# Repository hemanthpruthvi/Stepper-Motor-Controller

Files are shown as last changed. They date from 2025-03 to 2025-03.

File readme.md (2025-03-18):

# Generic Stepper Motor Controller for Multi-Axis Motion
The project describes a simple and complete solution to multi-axis motion control using generic stepper-motor based mounts with off-the-shelf motor drives, a system that looks like the following.  

Motion controller &rarr; Stepper motor drive &rarr; Motorized rotation/translation stage

The motion controller has two aspects:  
1. Hardware: design files for dsPIC micro-controller based custom board
2. Firmware: embedded-C program that implements the motion controls

## Hardware
The central element is a dsPIC micro-controller with two UART ports and several I/O ports that enable control of upto 3 drives at a time by sending correspinding pulse trains (drive IDs 1-3). Up to three of such motion controllers can be connected in daisy chain thus being able to control upto nine drives (drive IDs 1-9). The number of daisy chains is only a firmware limitation due to how the drives are numbered. A better numbering scheme should allow for more expansion.

The directory `Hardware` contains the design files. Hardware circuitry is designed using `KiCAD` program. The final `GERBER` file should be enough to produce the custom printed circuit boards.

## Firmware
The firmware is programmed in Embedded-C using `MPLABX IDE` with a header that is specific to the micro-controller of choice. The directory `Firmware` contains the source code as well as the compiled output. The firmware is written into the hardware using `PIKIT 3` programmer tool. The `HEX` file to be written to hardware is located at`<firmware directory>/dist/default/Production`.

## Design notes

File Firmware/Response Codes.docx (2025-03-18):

Stepper motor controller with home positioning sensor

1. Description

The stepper motor controller is designed to control three stepper motors corresponding to three rotation stages. It can be used to control linear stages as well but, as limit switch functionality is not provided, other precautions must be taken to facilitate it. It has dsPIC33fj128gp802 (https://www.microchip.com/wwwproducts/en/dsPIC33FJ128GP802) micro-controller. Two serial ports are provided: one communicate with slave & one with master. Up to three controllers can be used in tandem. Three motor controller ports are provided that include & homing detection too.

2. Sent Commands & responses

Configuration of serial port is baud rate: 115200, parity: N, stop bits: 1 and data bits: 8. Set of serial commands to operate the controller are given below. All the commands must start with ‘<’ and end with ‘>’ as shown in the table.

n: motor number (1, 2 or 3)

f: frequency of the pulses (1 to 2¹⁶-1)

p: number of pulses (1 to 2³²-1)

Command sent | Return | Function
<nH> | nH | Go gome in positive direction e.g., <1H>
<nh> | nh | Go home in the negative direction e.g., <1h>
<nQ> | nQ | Halt the motor e.g., <1Q>
<nFf> | nA | Change the frequency of the pulses i.e. speed e.g., <1F1000>
<n+p> | nA, nR | Rotate the motor by given number of pulses, in positive direction e.g., <1+1000>
<n-p> | nA, nR | Rotate the motor by given number of pulses, in negative direction e.g., <1-1000>

3. Responses & diagnosis

Possible responses and their cause is given below. All the responses are of 4 character length: two alphanumerical characters superseded by a newline character (‘\n’) and a null character (‘\0’). Hence, these responses can be read as lines.

Command received | Diagnosis
nH | Reached home in positive direction
nh | Reached home in negative direction
nQ | Motor halted
nA | Command is acknowledged
MA | Command is acknowledged by the master and it is forwarded to the slave controller
nR | All the pulses have been sent
nX | Motor number is right but wrong function command
MX | Wrong command altogether

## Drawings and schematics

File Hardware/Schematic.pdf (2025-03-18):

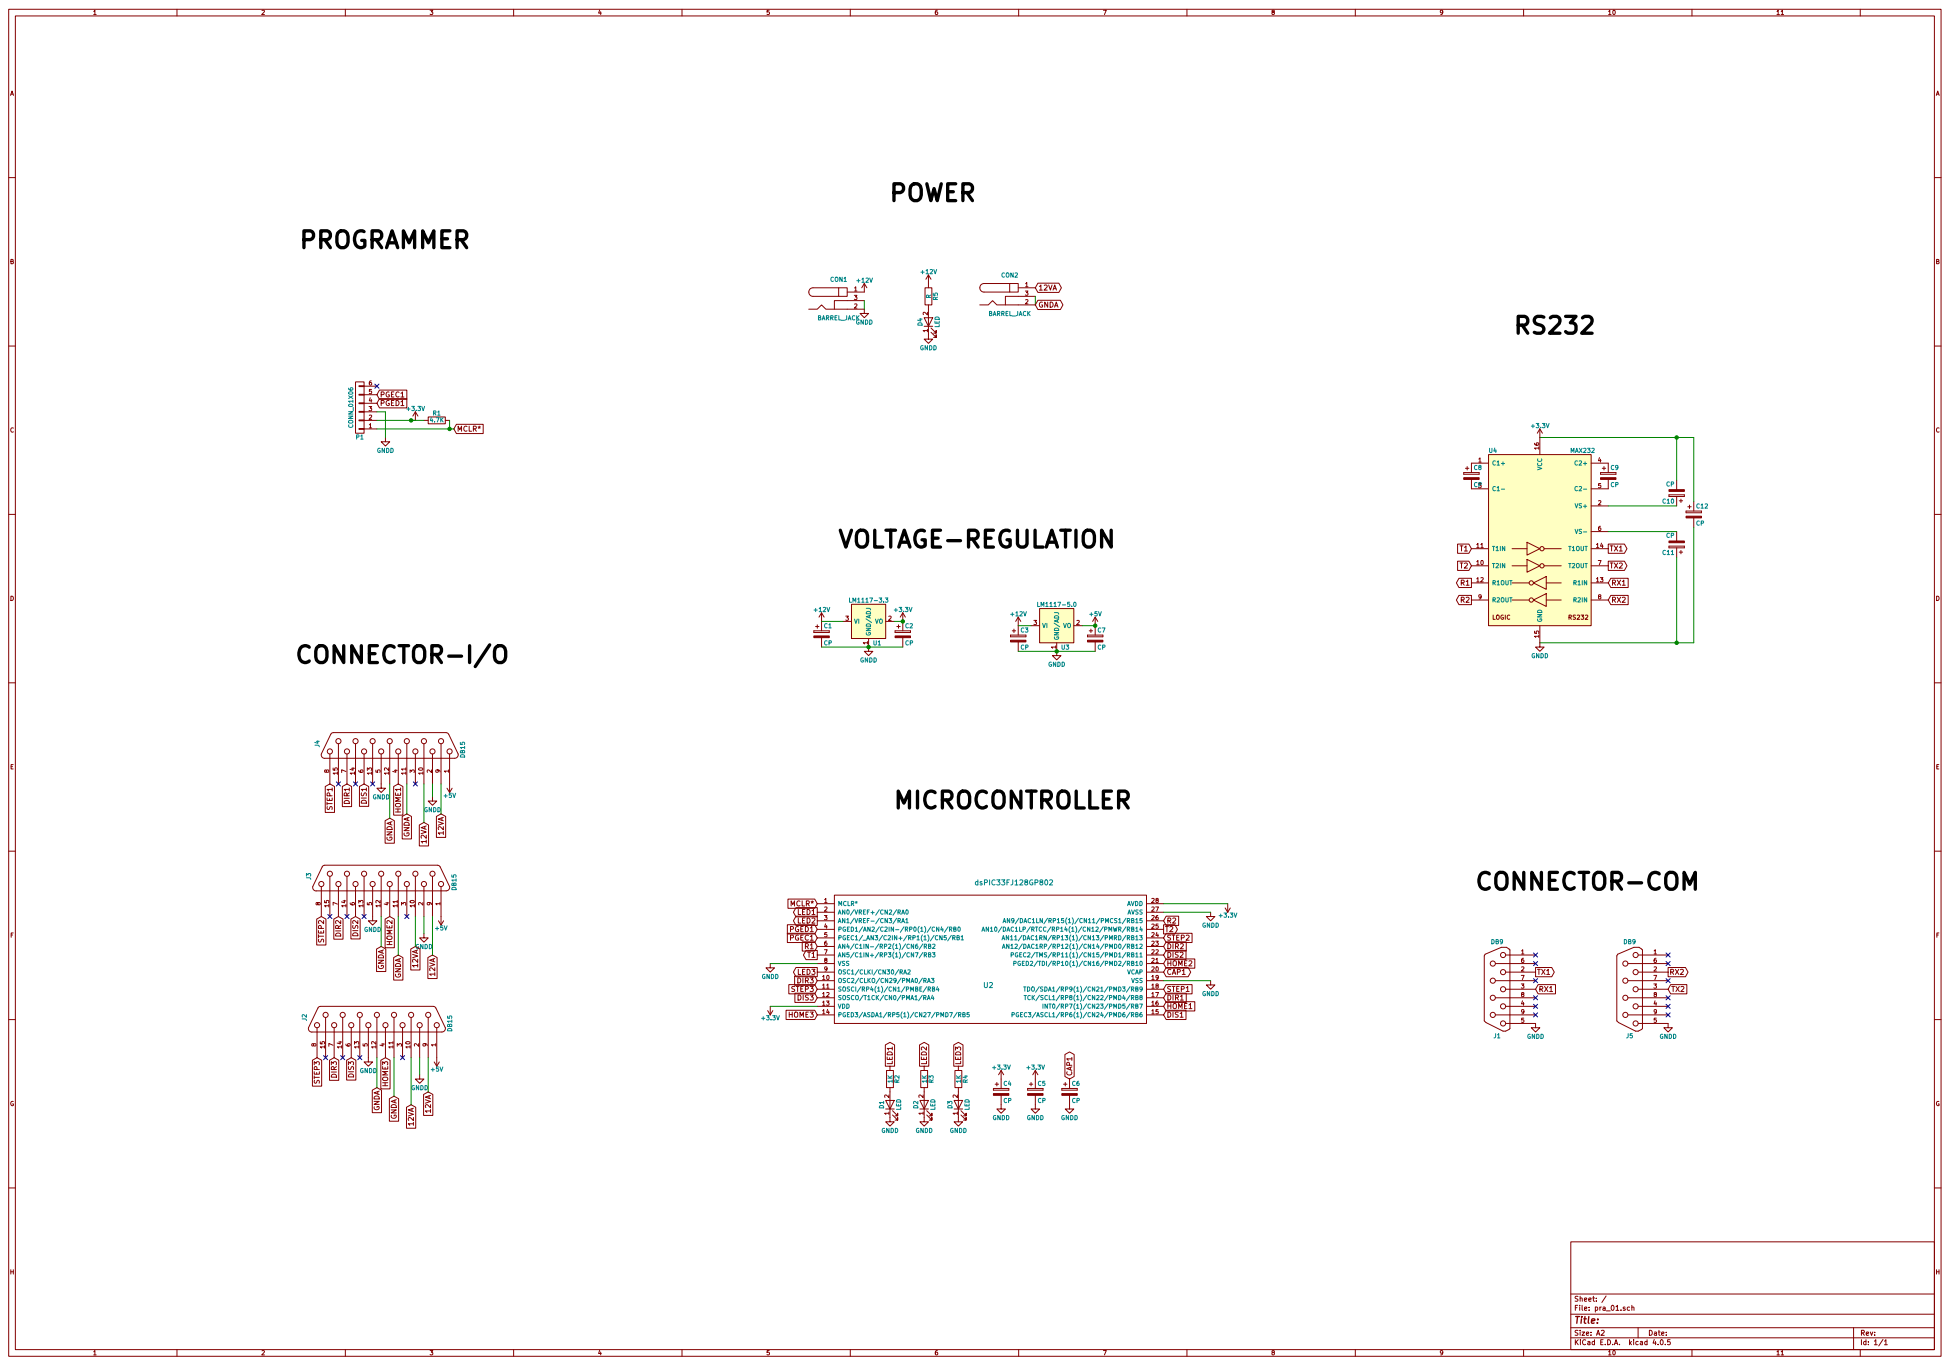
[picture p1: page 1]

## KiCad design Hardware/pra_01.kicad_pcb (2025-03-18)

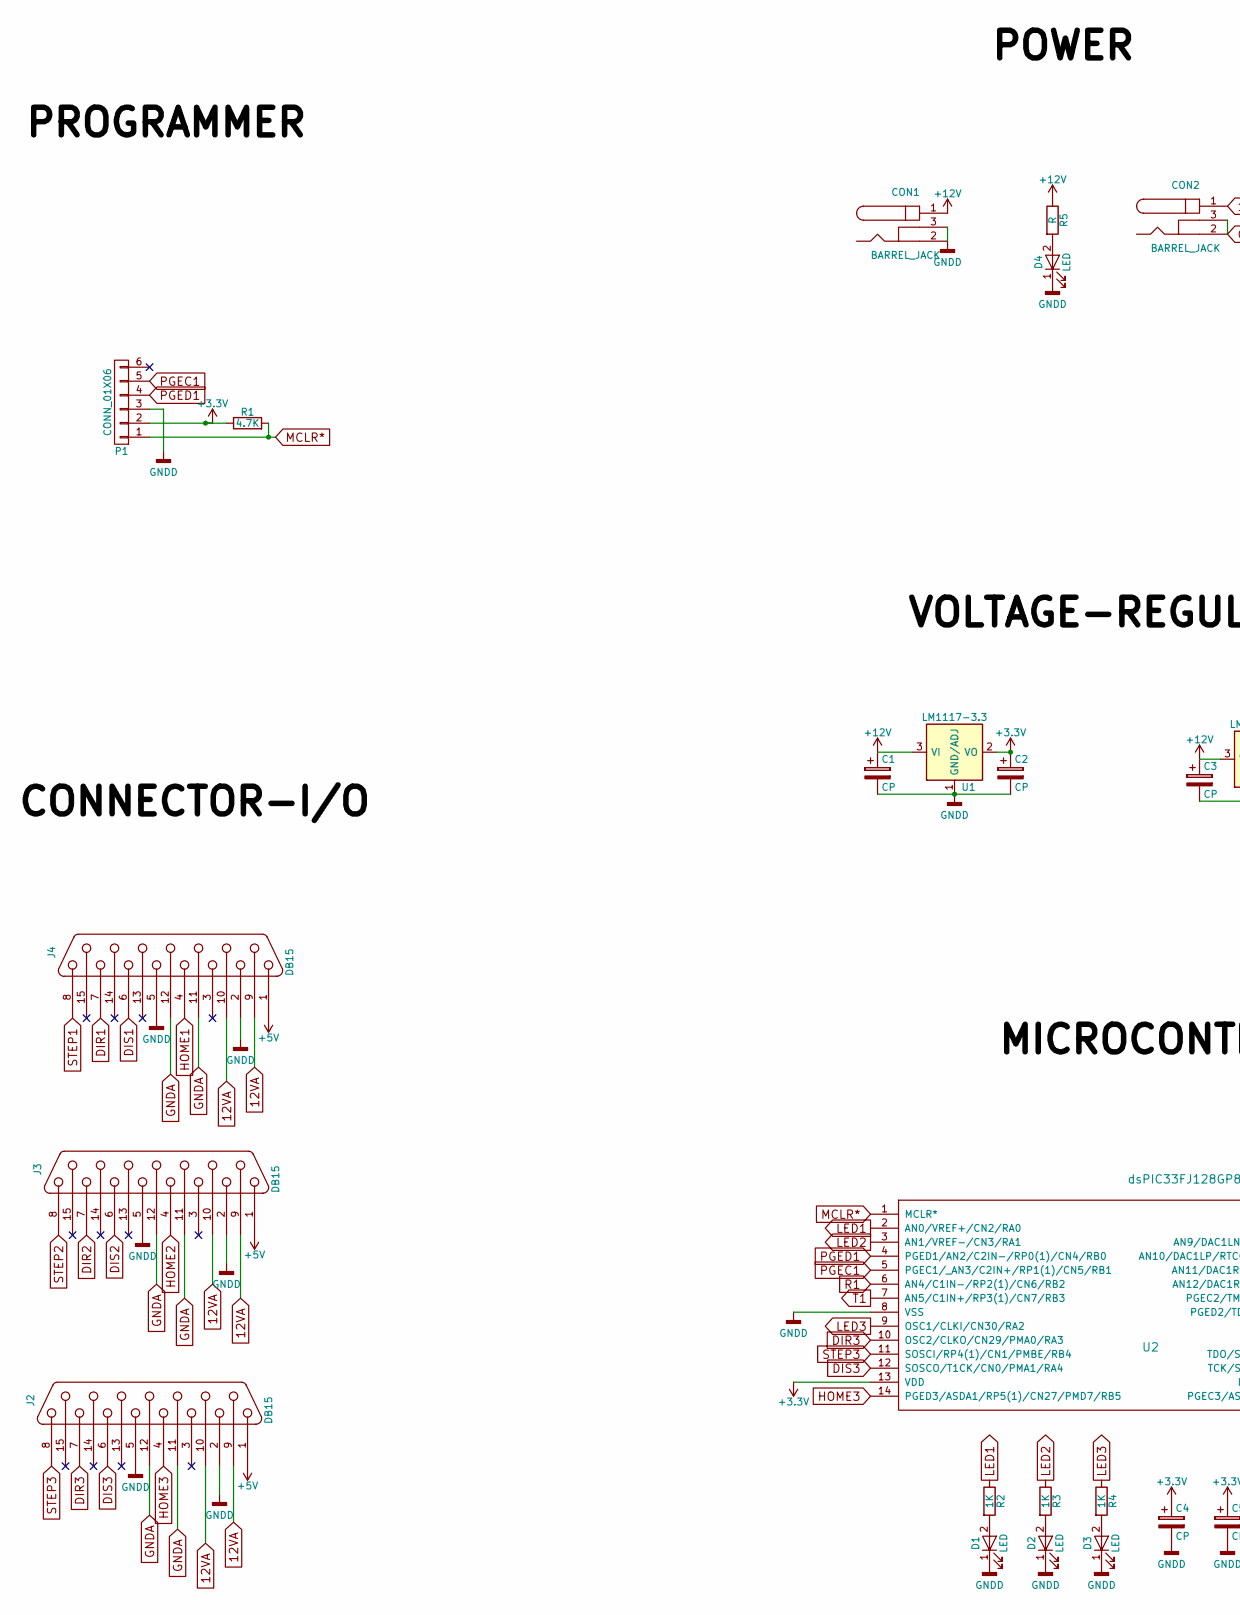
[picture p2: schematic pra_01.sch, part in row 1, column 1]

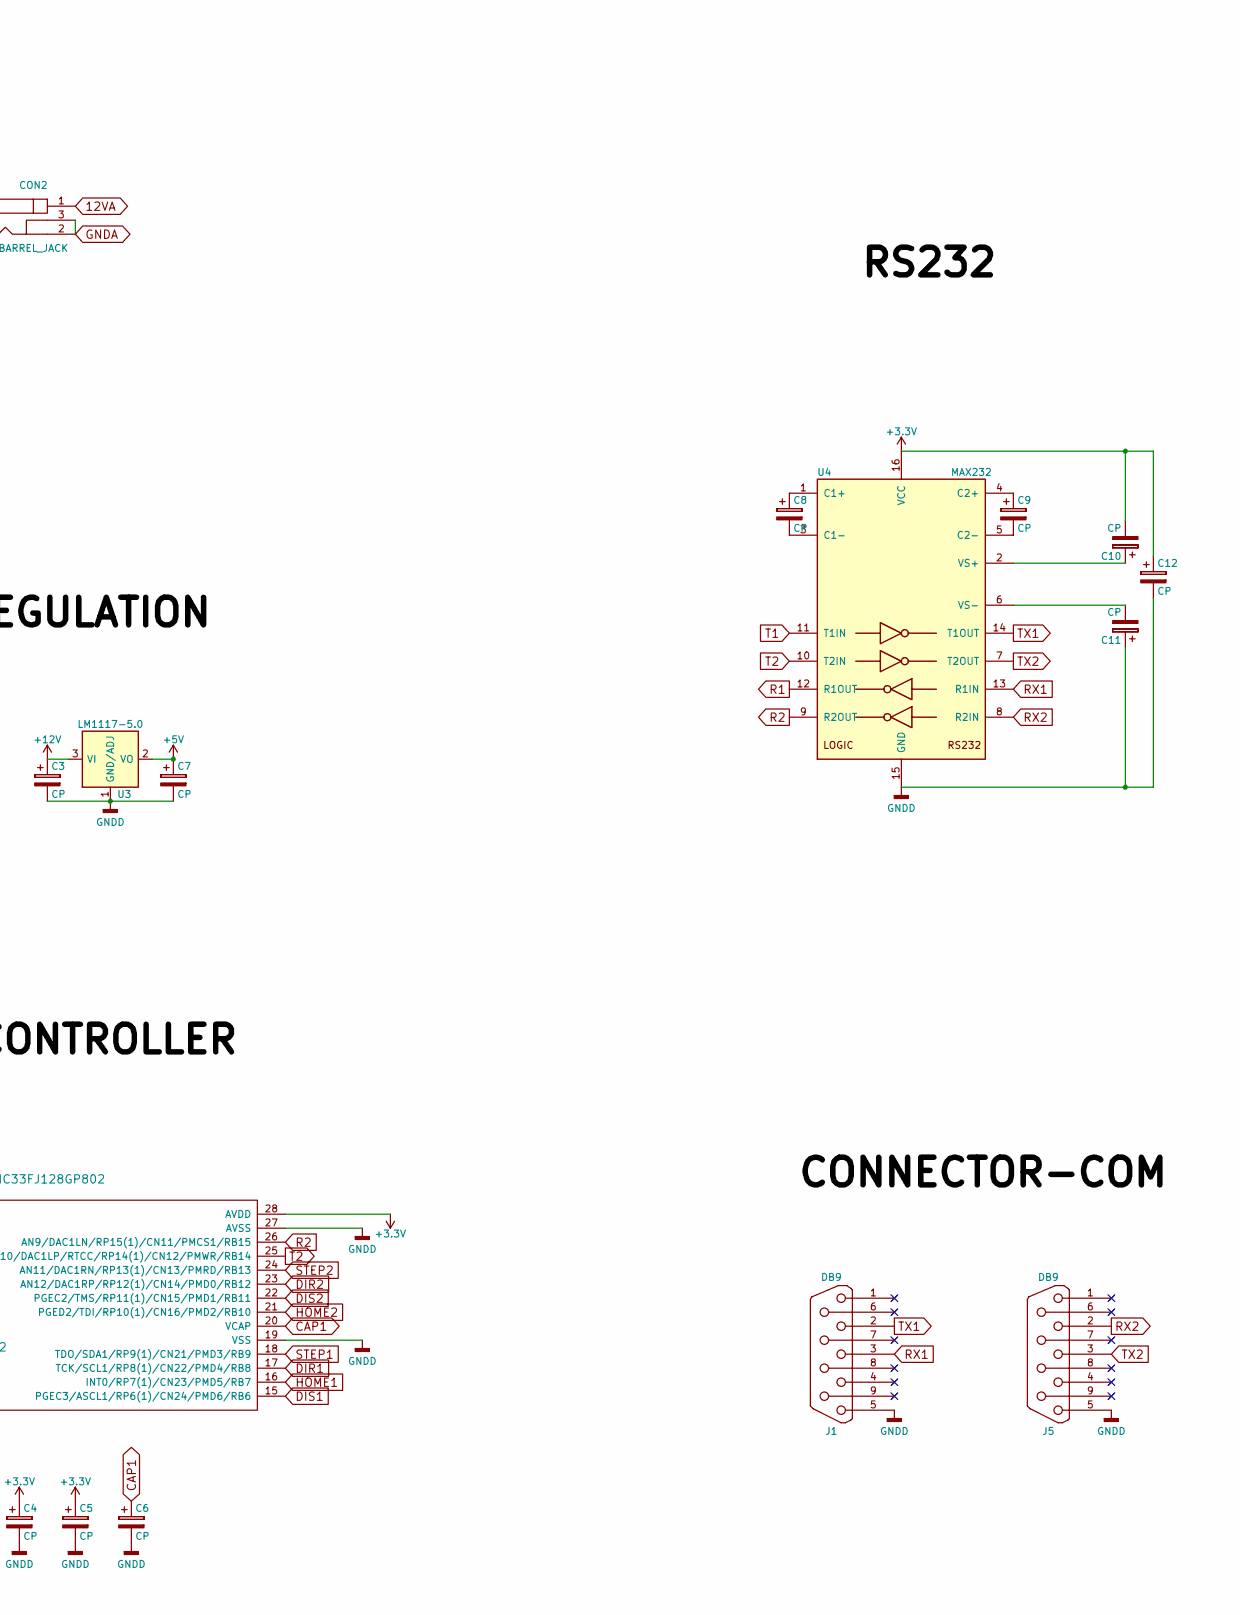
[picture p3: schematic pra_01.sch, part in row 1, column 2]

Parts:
C1, C2, C3, C6, C7: CP; CP_Radial_D5.0mm_P2.50mm
C4, C5, C8, C9, C10, C11, C12: CP; CP_Radial_Tantal_D5.0mm_P2.50mm
CON1, CON2: BARREL_JACK
D1, D2, D3: LED; LED_1206
D4: LED; LED_D5.0mm
J1: DB9; DB9FC
J2, J3, J4: DB15; DB15FC
J5: DB9; DB9MC
P1: CONN_01X06; PINHEAD1-6
R1: 4.7K; R_1206_HandSoldering
R2, R3, R4: 1K; R_1206_HandSoldering
R5: R; Resistor_SMD+THTuniversal_0805to1206_RM10_HandSoldering
U1: LM1117-3.3; TO-220
U2: dsPIC33FJ128GP802; DIP-28_W7.62mm
U3: LM1117-5.0; TO-220
U4: MAX232; DIP-16_W7.62mm_LongPads

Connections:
12VA: CON2.1, J2.9, J2.10, J3.9, J3.10, J4.9, J4.10
+3V3: C2.1, C4.1, C5.1, C10.2, C12.1, P1.2, R1.1, U1.2 (VO), U1.4 (VO), U2.13 (VDD), U2.28 (AVDD), U4.16 (VCC)
+5V: C7.1, J2.1, J3.1, J4.1, U3.2 (VO), U3.4 (VO)
+12V: C1.1, C3.1, CON1.1, R5.1, U1.3 (VI), U3.3 (VI)
CAP1: C6.1, U2.20 (VCAP)
DIR1: J4.7, U2.17 (TCK/SCL1/RP8(1)/CN22/PMD4/RB8)
DIR2: J3.7, U2.23 (AN12/DAC1RP/RP12(1)/CN14/PMD0/RB12)
DIR3: J2.7, U2.10 (OSC2/CLKO/CN29/PMA0/RA3)
DIS1: J4.6, U2.15 (PGEC3/ASCL1/RP6(1)/CN24/PMD6/RB6)
DIS2: J3.6, U2.22 (PGEC2/TMS/RP11(1)/CN15/PMD1/RB11)
DIS3: J2.6, U2.12 (SOSCO/T1CK/CN0/PMA1/RA4)
GNDA: CON2.2, CON2.3, J2.11 (P111), J2.12, J3.11 (P111), J3.12, J4.11 (P111), J4.12
GNDD: C1.2, C2.2, C3.2, C4.2, C5.2, C6.2, C7.2, C11.1, C12.2, CON1.2, CON1.3, D1.1 (K), D2.1 (K), D3.1 (K), D4.1 (K), J1.5, J2.2, J2.5, J3.2, J3.5, J4.2, J4.5, J5.5, P1.3, U1.1 (GND/ADJ), U2.8 (VSS), U2.19 (VSS), U2.27 (AVSS), U3.1 (GND/ADJ), U4.15 (GND)
HOME1: J4.4, U2.16 (INT0/RP7(1)/CN23/PMD5/RB7)
HOME2: J3.4, U2.21 (PGED2/TDI/RP10(1)/CN16/PMD2/RB10)
HOME3: J2.4, U2.14 (PGED3/ASDA1/RP5(1)/CN27/PMD7/RB5)
LED1: R2.1, U2.2 (AN0/VREF+/CN2/RA0)
LED2: R3.1, U2.3 (AN1/VREF-/CN3/RA1)
LED3: R4.1, U2.9 (OSC1/CLKI/CN30/RA2)
MCLR*: P1.1, R1.2, U2.1 (MCLR*)
unnamed: C8.1, U4.1 (C1+)
unnamed: C8.2, U4.3 (C1-)
unnamed: C9.1, U4.4 (C2+)
unnamed: C9.2, U4.5 (C2-)
unnamed: C10.1, U4.2 (VS+)
unnamed: C11.2, U4.6 (VS-)
unnamed: D1.2 (A), R2.2
unnamed: D2.2 (A), R3.2
unnamed: D3.2 (A), R4.2
unnamed: D4.2 (A), R5.2
PGEC1: P1.5, U2.5 (PGEC1/_AN3/C2IN+/RP1(1)/CN5/RB1)
PGED1: P1.4, U2.4 (PGED1/AN2/C2IN-/RP0(1)/CN4/RB0)
R1: U2.6 (AN4/C1IN-/RP2(1)/CN6/RB2), U4.12 (R1OUT)
R2: U2.26 (AN9/DAC1LN/RP15(1)/CN11/PMCS1/RB15), U4.9 (R2OUT)
RX1: J1.3, U4.13 (R1IN)
RX2: J5.2, U4.8 (R2IN)
STEP1: J4.8, U2.18 (TDO/SDA1/RP9(1)/CN21/PMD3/RB9)
STEP2: J3.8, U2.24 (AN11/DAC1RN/RP13(1)/CN13/PMRD/RB13)
STEP3: J2.8, U2.11 (SOSCI/RP4(1)/CN1/PMBE/RB4)
T1: U2.7 (AN5/C1IN+/RP3(1)/CN7/RB3), U4.11 (T1IN)
T2: U2.25 (AN10/DAC1LP/RTCC/RP14(1)/CN12/PMWR/RB14), U4.10 (T2IN)
TX1: J1.2, U4.14 (T1OUT)
TX2: J5.3, U4.7 (T2OUT)

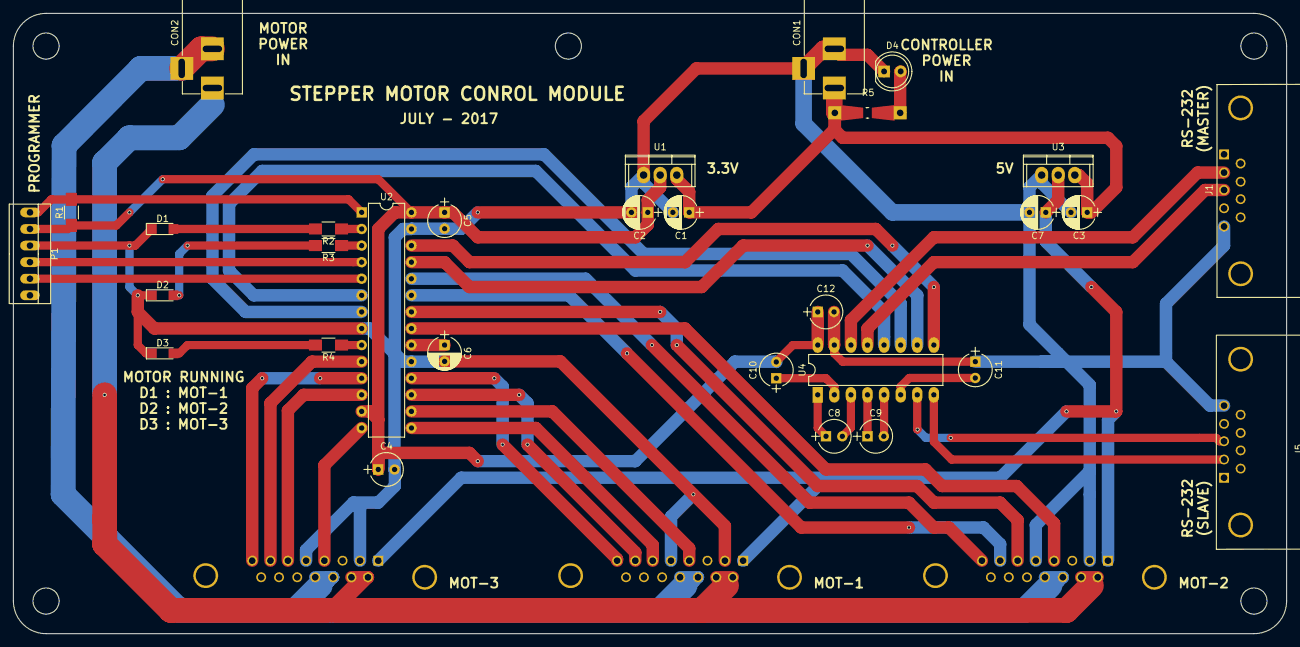
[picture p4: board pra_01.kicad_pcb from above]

Board: 2 copper layers, 195.0 x 95.0 mm, 33 parts (0 on the bottom side), 43 nets.

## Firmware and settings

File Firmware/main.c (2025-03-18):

/* 
 * File:   uart.c
 * Author: Pruthvi
 *
 * Created on June 2, 2014, 5:38 PM
 */
#include <p33FJ128GP802.h>
#include <stdio.h>
#include <stdlib.h>
#include "config.h"

unsigned char COMMAND[16];   // Command array
unsigned char SLAVE_COMMAND[16]; // Command array for slave
unsigned int COMM_IND = 0;       // Command array index
unsigned int COMM_LEN = 0;       // Command length
unsigned int COMM_REC = NO;       // Command received?
unsigned char SRESPONSE[4];
unsigned char MRESPONSE[4];

unsigned int NUMBER_MOTO = '0';    // Motor number
unsigned int FUNCTION_MOTO = '0';  // Function of drivers
unsigned long int NUMBER = 0;         // Numerical value

unsigned int MOT1_ROTAT = OFF; // Motor-1 rotation?
unsigned int MOT1_HOME = OFF;  // Motor-1 homing?
unsigned long int STEP1_NUM = 0;  // Number of steps left
unsigned long int HSTEP1_NUM = 0; // Number of toggles (half-steps)  = 2* Number of steps
unsigned int STEP1_FREQ = 1000; // Step frequency
unsigned long int POS1_CURRENT = 0; // Current value - 1

unsigned int MOT2_ROTAT = OFF; // Motor-2 rotation?
unsigned int MOT2_HOME = OFF;  // Motor-2 homing?
unsigned long int STEP2_NUM = 0;  // Number of steps left
unsigned long int HSTEP2_NUM = 0; // Number of toggles (half-steps) = 2* Number of steps
unsigned int STEP2_FREQ = 1000; // Step frequency
unsigned long int POS2_CURRENT = 0; // Current value - 2


unsigned int MOT3_ROTAT = OFF; // Motor-3 rotation?
unsigned int MOT3_HOME = OFF;  // Motor-3 homing?
unsigned long int STEP3_NUM = 0;  // Number of steps left
unsigned long int HSTEP3_NUM = 0; // Number of toggles (half-steps) = 2* Number of steps
unsigned int STEP3_FREQ = 1000; // Step frequency
unsigned long int POS3_CURRENT = 0; // Current value - 3

#pragma config POSCMD = NONE   // Primary Oscillator Mode is None
#pragma config OSCIOFNC = ON   // Oscillator pin's I/O Funcion - On
#pragma config FCKSM = CSDCMD  // Clock Switching & Monitoring - Both Disabled
#pragma config FNOSC = FRCPLL  // Oscillator select - FastRC with PLL
#pragma config FWDTEN = OFF    // Watch Dog Timer Enable - Off

void PROCESS_COMM(void);
void DELAY(int);

int main(void){
    ADPCFG = 0xFFFF;    //make ADC pins all digital
    INIT_OSCLI();   // Initiate =internal Oscillator
    INIT_INOUT();   // Input/Output
    INIT_UART1();   // UART-1
    INIT_UART2();   // UART-2
    INIT_TIMR2();   // Timer-2
    INIT_TIMR3();   // Timer-2
    INIT_TIMR4();   // Timer-2
    INIT_INTRR();   // External interrupts
    // Default Motor Speeds
    T2CONbits.TON = 0;		// Disable Timer
    PR2 = ((FCY/64)/2)/STEP1_FREQ;
    T2CONbits.TON = 1;		// Enable Timer
    T3CONbits.TON = 0;		// Disable Timer
    PR3 = ((FCY/64)/2)/STEP2_FREQ;
    T3CONbits.TON = 1;		// Enable Timer
    T4CONbits.TON = 0;		// Disable Timer
    PR4 = ((FCY/64)/2)/STEP3_FREQ;
    T4CONbits.TON = 1;		// Enable Timer
    while(1){
        // Command Processing
        if (COMM_REC){ // If command is received in UART-1
            PROCESS_COMM();
            MRESPONSE[2] = '\n';
            MRESPONSE[3] = '\0';
            U1TX_SENDSTR(MRESPONSE);
            COMM_REC = NO;
        }
    }
    return 0;
}

void DELAY(int temp){
    int i=0, j=0;
    for (i=0;i<2000;i++)
            for(j=0;j<temp;j++);
}

void PROCESS_COMM(void){
	unsigned int i;
	char temp;
    temp = COMMAND[0]-'0';
    if (temp > 3 && temp < 7){ // Check if the COMMAND is for the slave
        SLAVE_COMMAND[0] = '<';
        SLAVE_COMMAND[1] = COMMAND[0]-3;
        for (i = 1; COMMAND[i] != '\0'; i++){
            SLAVE_COMMAND[i+1] = COMMAND[i];
            SLAVE_COMMAND[i+2] = '>';
        }        
        U2TX_SENDSTR(SLAVE_COMMAND);
        MRESPONSE[0] = 'M'; 
        MRESPONSE[1] = 'A'; // 'A' for acknowledge
        return;
    }
    
    else{ // COMMAND is for the master
        NUMBER_MOTO = COMMAND[0];       // Corresponding motor (1, 2 or 3)
        FUNCTION_MOTO = COMMAND[1];     // Function? (Rotate or adjust speed)
        NUMBER = 0;
        for(i = 2; COMMAND[i] != '\0'; i++){    // Numerical value
            temp = COMMAND[i] - '0';
            if (temp < 0 || temp > 9){
                NUMBER = 0;
                MRESPONSE[0] = 'M'; 
                MRESPONSE[1] = 'X'; // 'X' for wrong
                return;
            }
            NUMBER = (NUMBER*10)+ temp;
        }
        // Execute the function for the motor      
        switch (COMMAND[0]){
            // Command for motor-1
            case '1':
                MRESPONSE[0] = '1';
                if (COMMAND[1] == 'Q') {
                    MOT1_ROTAT = OFF;
                    MOT1_HOME = OFF;
                    LED1 = OFF; 
                    MRESPONSE[1] = 'Q'; // 'Q' for quitting
                    return;
                }
                else if (MOT1_ROTAT == YES || MOT1_HOME == YES){ 
                    MRESPONSE[1] = 'B'; // 'B' for busy
                    return;
                }
                else{
                    switch (COMMAND[1]){
                        case 'D':
                            DIS1 = 1;
                            MRESPONSE[1] = 'D'; // 'D' for disable 
                            return;
                        case 'E':
                            DIS1 = 0;
                            MRESPONSE[1] = 'E'; // 'E' for enable 
                            return;
                        case 'H':
                            STEP1_NUM = 10000000;
                            HSTEP1_NUM = 2*STEP1_NUM;
                            DIR1 = 1;
                            MOT1_HOME = ON;
                            MOT1_ROTAT = ON;
                            MRESPONSE[1] = 'A'; // 'A' for acknowledge 
                            return;
                        case 'h': 
                            STEP1_NUM = 10000000;
                            HSTEP1_NUM = 2*STEP1_NUM;
                            DIR1 = 0;
                            MOT1_HOME = ON;
                            MOT1_ROTAT = ON;
                            MRESPONSE[1] = 'A'; // 'A' for acknowledge 
                            return;
                        case'F':
                            STEP1_FREQ = NUMBER; // STEP FREQUENCY
                            T2CONbits.TON = 0;		// Disable Timer
                            PR2 = ((FCY/64)/2)/STEP1_FREQ;
                            T2CONbits.TON = 1;		// Enable Timer
                            MRESPONSE[1] = 'A'; // 'A' for acknowledge 
                            return;
                        case '+':
                            if (NUMBER == 0){
                                MRESPONSE[1] = 'R';
                                return;
                            }
                            STEP1_NUM = NUMBER;
                            HSTEP1_NUM = 2*STEP1_NUM;
                            DIR1 = 0;
                            MOT1_ROTAT = ON;
                            MRESPONSE[1] = 'A'; // 'A' for acknowledge 
                            return;
                        case '-':
                            if (NUMBER == 0){
                                MRESPONSE[1] = 'R';
                                return;
                            }
                            STEP1_NUM = NUMBER;
                            HSTEP1_NUM = 2*STEP1_NUM;
                            DIR1 = 1;
                            MOT1_ROTAT = ON;
                            MRESPONSE[1] = 'A'; // 'A' for acknowledge 
                            return;
                        default:
                            MRESPONSE[1] = 'X'; // 'X' for wrong 
                            return;
                    }
                }
            // End of Case-1   
                
            // Command for motor-2
            case '2':
                MRESPONSE[0] = '2';
                if (COMMAND[1] == 'Q') {
                    MOT2_ROTAT = OFF;
                    MOT2_HOME = OFF;
                    LED2 = OFF;
                    MRESPONSE[1] = 'Q'; // 'Q' for quitting 
                    return;
                }
                else if (MOT2_ROTAT == YES || MOT2_HOME == YES){
                    MRESPONSE[1] = 'B'; // 'A' for acknowledge 
                    return; // 'B' for busy
                }
                else{
                    switch (COMMAND[1]){
                        case 'D':
                            DIS2 = 1;
                            MRESPONSE[1] = 'D'; // 'D' for disable 
                            return;
                        case 'E':
                            DIS2 = 0;
                            MRESPONSE[1] = 'E'; // 'E' for enable 
                            return;
                        case 'H':
                            STEP2_NUM = 10000000;
                            HSTEP2_NUM = 2*STEP2_NUM;
                            DIR2 = 1;
                            MOT2_HOME = ON;
                            MOT2_ROTAT = ON;
                            MRESPONSE[1] = 'A'; // 'A' for acknowledge 
                            return;
                        case 'h': 
                            STEP2_NUM = 10000000;
                            HSTEP2_NUM = 2*STEP2_NUM;
                            DIR2 = 0;
                            MOT2_HOME = ON;
                            MOT2_ROTAT = ON;
                            MRESPONSE[1] = 'A'; // 'A' for acknowledge 
                            return;
                        case'F':
                            STEP2_FREQ = NUMBER; // STEP FREQUENCY
                            T3CONbits.TON = 0;		// Disable Timer
                            PR3 = ((FCY/64)/2)/STEP2_FREQ;
                            T3CONbits.TON = 1;		// Enable Timer
                            MRESPONSE[1] = 'A'; // 'A' for acknowledge 
                            return;
                        case '+':
                            if (NUMBER == 0){
                                MRESPONSE[1] = 'R';
                                return;
                            }
                            STEP2_NUM = NUMBER;
                            HSTEP2_NUM = 2*STEP2_NUM;
                            DIR2 = 0;
                            MOT2_ROTAT = ON;
                            MRESPONSE[1] = 'A';
                            return;
                        case '-':
                            if (NUMBER == 0){
                                MRESPONSE[1] = 'R';
                                return;
                            }
                            STEP2_NUM = NUMBER;
                            HSTEP2_NUM = 2*STEP2_NUM;
                            DIR2 = 1;
                            MOT2_ROTAT = ON;
                            MRESPONSE[1] = 'A'; // 'A' for acknowledge 
                            return;
                        default:
                            MRESPONSE[1] = 'X'; // 'X' for wrong 
                            return;
                    }
                }
            // End of Case-2
                
            // Command for motor-3
            case '3':
                MRESPONSE[0] = '3';
                if (COMMAND[1] == 'Q') {
                    MOT3_ROTAT = OFF;
                    MOT3_HOME = OFF;
                    LED3 = OFF;
                    MRESPONSE[1] = 'Q'; // 'Q' for quitting 
                    return;
                }
                else if (MOT3_ROTAT == YES || MOT3_HOME == YES){
                    MRESPONSE[1] = 'B'; // 'B' for busy 
                    return;
                }
                else{
                    switch (COMMAND[1]){
                        case 'D':
                            DIS3 = 1;
                            MRESPONSE[1] = 'D'; // 'D' for disable 
                            return;
                        case 'E':
                            DIS3 = 0;
                            MRESPONSE[1] = 'E'; // 'E' for enable 
                            return;
                        case 'H':
                            if (POS3_CURRENT == 0){
                                MRESPONSE[1] = 'H';
                                return;
                            }
                            STEP3_NUM = 10000000;
                            HSTEP3_NUM = 2*STEP3_NUM;
                            DIR3 = 1;
                            MOT3_HOME = ON;
                            MOT3_ROTAT = ON;
                            MRESPONSE[1] = 'A'; // 'A' for acknowledge 
                            return;
                        case 'h':
                            STEP3_NUM = 10000000;
                            HSTEP3_NUM = 2*STEP3_NUM;
                            DIR3 = 0;
                            MOT3_HOME = ON;
                            MOT3_ROTAT = ON;
                            MRESPONSE[1] = 'A'; // 'A' for acknowledge 
                            return;
                        case 'I':
                            STEP3_NUM = 1000;
                            HSTEP3_NUM = 2*STEP3_NUM;
                            DIR3 = 0;
                            MOT3_ROTAT = ON;
                            MRESPONSE[1] = 'A'; // 'A' for acknowledge 
                            return;
                        case'F':
                            STEP3_FREQ = NUMBER; // STEP FREQUENCY
                            T4CONbits.TON = 0;		// Disable Timer
                            PR4 = ((FCY/64)/2)/STEP3_FREQ;
                            T4CONbits.TON = 1;		// Enable Timer
                            MRESPONSE[1] = 'A'; // 'A' for acknowledge 
                            return;
                        case '+':
                            if (NUMBER == 0){
                                MRESPONSE[1] = 'R';
                                return;
                            }
                            STEP3_NUM = NUMBER;
                            HSTEP3_NUM = 2*STEP3_NUM;
                            DIR3 = 0;
                            MOT3_ROTAT = ON;
                            MRESPONSE[1] = 'A';
                            return;
                        case '-':
                            if (NUMBER == 0){
                                MRESPONSE[1] = 'R';
                                return;
                            }
                            if (POS3_CURRENT == 0){
                                MRESPONSE[1] = 'H';
                                return;
                            }
                            STEP3_NUM = NUMBER;
                            HSTEP3_NUM = 2*STEP3_NUM;
                            DIR3 = 1;
                            MOT3_ROTAT = ON;
                            MRESPONSE[1] = 'A'; // 'A' for acknowledge 
                            return;
                        default:
                            MRESPONSE[1] = 'X'; // 'X' for wrong
                            return;
                    }
                }
            // End of Case-3   
            
            default:
                MRESPONSE[0] = 'M';
                MRESPONSE[1] = 'X'; // 'X' for wrong
                return;
        }
        MRESPONSE[0] = 'M';
        MRESPONSE[1] = 'X'; // 'X' for wrong
        return;
    }
}

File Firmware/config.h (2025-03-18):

/* 
 * File:   
 * Author: 
 * Comments:
 * Revision history: 
 */ 
#ifndef XC_CONFIG_H
    #define	XC_CONFIG_H
    #include <xc.h> // include processor files - each processor file is guarded
    #include <p33FJ128GP802.h>

// Define required parameters
    // Internal oscillator
    #define FOSC (80000000) // Oscillator frequency (approx.)(To be set)
    #define FCY (FOSC/2)    // Peripheral clock frequency (To be set
    // Timers
    #define TIMER_VAL(FREQ) ((FCY/64)/2)/FREQ) // To be given by user
    // UARTs
    #define BAUDRATE1 (115200)
    #define WAIT_TX1 (FCY/BAUDRATE1)
    #define BRGVAL1 (((FCY/BAUDRATE1)/16)-1) 
    #define BAUDRATE2 (115200)
    #define WAIT_TX2 (FCY/BAUDRATE2)
    #define BRGVAL2 (((FCY/BAUDRATE2)/16)-1) 
    // LEDs
    #define LED1 LATAbits.LATA0
    #define LED2 LATAbits.LATA1
    #define LED3 LATAbits.LATA2
    // Motor-1 controls
    #define STEP1 LATBbits.LATB9
    #define DIR1 LATBbits.LATB8
    #define DIS1 LATBbits.LATB6 
    // Motor-2 controls
    #define STEP2 LATBbits.LATB13
    #define DIR2 LATBbits.LATB12
    #define DIS2 LATBbits.LATB11
    // Motor-3 controls
    #define STEP3 LATBbits.LATB4
    #define DIR3 LATAbits.LATA3
    #define DIS3 LATAbits.LATA4

// Define initialization functions for modules
    // Initialize Oscillator
    void INIT_OSCLI(void);    
    // Initialize timers
    void INIT_TIMR2(void);    
    void INIT_TIMR3(void);
    void INIT_TIMR4(void);
    // Initialize UARTs
    void INIT_UART1(void);
    void INIT_UART2(void);
    // Initialize I/O pins
    void INIT_INOUT(void);
    // Initialize External interrupts
    void INIT_INTRR(void);
    
    //  Define custom functions
    void U1TX_SENDCHR(unsigned char);
    void U1TX_SENDSTR(unsigned char *);
    void U2TX_SENDCHR(unsigned char);
    void U2TX_SENDSTR(unsigned char *);
    
// Define commonly used symbols here
    #define FIRST_CHAR '<'  // Command's first character
    #define LAST_CHAR '>'   // Command's last character
    #define YES 1
    #define NO 0
    #define ON 1
    #define OFF 0

// Declare global variables
    extern unsigned char COMMAND[16];   // Command array
    extern unsigned char SLAVE_COMMAND[16]; // Command array for slave
    extern unsigned int COMM_IND;       // Command array index
    extern unsigned int COMM_LEN;       // Command length
    extern unsigned int COMM_REC;       // Command received?
    extern unsigned char SRESPONSE[4];   // Slave Response for the commands, 3rd char is always '\n'
    extern unsigned char MRESPONSE[4];   // Master Response for the commands, 3rd char is always '\n'
    
    extern unsigned int NUMBER_MOTO;    // Motor number
    extern unsigned int FUNCTION_MOTO;  // Function of drivers
    extern unsigned long int NUMBER;         // Numerical value
    
    extern unsigned int MOT1_ROTAT; // Motor-1 rotation?
    extern unsigned int MOT1_HOME;  // Motor-1 homing?
    extern unsigned long int STEP1_NUM;  // Number of steps left
    extern unsigned long int HSTEP1_NUM; // Number of toggles (half-steps)  = 2* Number of steps
    extern unsigned int STEP1_FREQ; // Step frequency
    extern unsigned long int POS1_CURRENT; // Current value - 1
   
    extern unsigned int MOT2_ROTAT; // Motor-2 rotation?
    extern unsigned int MOT2_HOME;  // Motor-2 homing?
    extern unsigned long int STEP2_NUM;  // Number of steps left
    extern unsigned long int HSTEP2_NUM; // Number of toggles (half-steps) = 2* Number of steps
    extern unsigned int STEP2_FREQ; // Step frequency
    extern unsigned long int POS2_CURRENT; // Current value - 2

    
    extern unsigned int MOT3_ROTAT; // Motor-3 rotation?
    extern unsigned int MOT3_HOME;  // Motor-3 homing?
    extern unsigned long int STEP3_NUM;  // Number of steps left
    extern unsigned long int HSTEP3_NUM; // Number of toggles (half-steps) = 2* Number of steps
    extern unsigned int STEP3_FREQ; // Step frequency
    extern unsigned long int POS3_CURRENT; // Current value - 3
#endif	/* XC_CONFIG_H */
